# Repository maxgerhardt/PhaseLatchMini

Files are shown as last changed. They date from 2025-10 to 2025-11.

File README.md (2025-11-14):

# PhaseLatch Mini – STM32F103 Dual-ADC IQ USB Streamer

> Combined hardware + firmware + host tooling for a compact dual‑ADC I/Q capture platform.

## Overview

High-rate continuous streaming of interleaved dual ADC (I/Q) samples over USB Full‑Speed (FS) using only the built‑in CDC class on an STM32F103C8 ("Blue Pill" style) board. Companion Python host tools provide live visualization, FIFO bridging, raw capture, diagnostics, and throughput benchmarking.

> Status: Actively optimized. Current configured complex sample rate target: **210.5 k I/Q samples/sec** (`IQ_SAMPLE_RATE_HZ` = 210526) with sustained USB payload throughput >500 KiB/s. Timer PSC/ARR are selected at runtime by a search routine for the closest achievable rate; observed effective rate can be within a small delta of the target. ADC sampling time was reduced (now `ADC_SAMPLETIME_28CYCLES_5`) to reach this rate while maintaining conversion stability.

> Origin / Intended Use: Initially developed as a lightweight streaming engine for the [PhaseLoom](https://github.com/AndersBNielsen/PhaseLoom) project, but fully usable with any dual (I/Q) analog front end producing baseband signals on two STM32F1 ADC channels. 
Note: Phaseloom should be modified for best performance. Replace 22kOhm feedback caps with matched 47kOhm resistors and replace the output stage 50 ohms with 0 ohm.

https://www.youtube.com/watch?v=UEAtSE1PV44

---
## Hardware: PhaseLatch Mini
A 4‑layer purple PCB (Blue Pill footprint inspired) integrating two SMA input ports and on‑board ~100 kHz low‑pass filtering (~210 kHz complex baseband bandwidth). Designed around the STM32F103C8 in dual regular simultaneous ADC mode (ADC1 + ADC2) to stream interleaved I/Q samples over USB Full-Speed.

PhaseLatch Mini

### Key Features
- MCU: STM32F103C8 (72 MHz) LQFP‑48
- Dual simultaneous ADC (12‑bit each) packed into 32‑bit words (I lower 12 bits, Q upper 12 bits)
- 2 × edge‑mount SMA (J20 = I_IN, J21 = Q_IN)
- Integrated passive input filtering (inductor + capacitor network targeting ~100 kHz LPF per channel)
- USB‑C connector (USB2.0 FS, CDC class currently; raw/bulk class option planned)
- On‑board 8 MHz + 32.768 kHz crystals for stable system and RTC timing
- Ferrite bead + local bulk/decoupling for cleaner ADC rails
- Unused GPIOs forced to analog mode early for noise reduction (see `Quiet_Unused_Pins` in `main.c`)
- Headers for expansion / SWD / boot configuration

### Production Assets
All fabrication outputs live in `hardware/PhaseLatchMini/production`:
- `PhaseLatchMini.zip` – Gerber/drill bundle ready for PCB fab
- `bom.csv` – Bill of Materials (with LCSC part numbers for quick JLCPCB sourcing)
- `designators.csv` – Component reference list
- `positions.csv` – Pick‑and‑place XY + rotation for SMT assembly
- `netlist.ipc` – IPC netlist export

Direct link (relative): `hardware/PhaseLatchMini/production/PhaseLatchMini.zip`

### BOM Highlights
Representative components (from `bom.csv`):
- Decoupling: multiple 100 nF 0402 caps (C307331) near MCU and filter sections
- Filter / bulk caps: 22 nF, 220 nF, 470 nF mix shaping input response
- Inductors: six 10 µH (0805) parts forming LC sections for each channel’s low‑pass filtering / supply isolation
- USB-C receptacle: 16‑pin (HCTL HC-TYPE-C-16P-01A) with 5k1 CC resistors for proper orientation detection
- Ferrite bead (FB1) for USB / supply noise suppression
- Voltage regulator: MIC5504-3.3 (SOT‑23‑5) providing clean 3V3
- Crystals: 8 MHz main, 32.768 kHz low‑speed (RTC / optional precise timing)
- SMA edge connectors: matched pair for I and Q inputs

### Assembly Notes
- Clean flux residues near high‑impedance analog nodes (C1/C8 cluster) to keep leakage low.
- If performing hand assembly, solder the SMA edge connectors first to anchor board alignment, then USB, then fine‑pitch MCU.

### Filter Tuning
Current passive network targets ~100 kHz corner. For alternative bandwidths:
- Raise corner: decrease shunt capacitance (e.g., swap 470 nF → 220 nF or 22 nF depending on desired slope) or reduce inductance value.
- Lower corner: increase shunt capacitance or employ higher inductance (space permitting). Recalculate fc ≈ 1/(2π√(L·C_eq)).
- Mitigate source‑resistor induced tilt: include its resistance in design equations; keep initial shunt capacitors modest (≤10 nF) if a 50 Ω series is retained upstream.

## Firmware

- Dual ADC synchronous sampling packed as 32-bit little-endian words (I 12-bit + Q 12-bit inside two 16-bit lanes)
- Target sample rate `IQ_SAMPLE_RATE_HZ` (currently 210526) with dynamic TIM3 prescaler/period search (see `timer_trigger_init()` in `iq_adc.c`)
- ADC sampling time set to `ADC_SAMPLETIME_28CYCLES_5` for higher throughput (previous higher value limited rate)
- Circular DMA with half / full transfer interrupts
- Lock-free ring queue feeding USB transmit path
- ISR burst chaining (current chain limit 16 packets per IN completion) to minimize USB idle gaps
- Immediate DMA IRQ packet scheduling ("kick") to prime first packet of each half-buffer
- Optional diagnostic/stat packets suppressed in throughput builds
- Host tools for diagnostics, throughput, raw capture, FIFO bridging, live view

### Changing the Sample Rate
1. Edit `Inc/iq_adc.h` and set `#define IQ_SAMPLE_RATE_HZ <desired_rate>` (I/Q pairs per second).
2. Ensure the new rate is feasible: TIM3 must be able to realize it given 16-bit ARR and prescaler; the search code picks the closest achievable value.
3. If pushing higher rates:
   - Consider reducing ADC sampling time (`ADC_SAMPLETIME_x`) further, but watch noise/performance.
   - Monitor USB throughput counters (`FEED` command) for increased busy skips.
4. Rebuild and flash. Optionally measure actual achieved rate by counting `iq_dma_half_count` + `iq_dma_full_count` over a timed host interval.

### Verifying Achieved Rate
- After START, issue the `A` command periodically; note increments of half/full counts.
- Effective samples/sec ≈ ((delta_half + delta_full) * half_buffer_samples) / time_interval.
- Or capture a known duration with `host_test.py` and compute rows * rate.

---
## Repository Layout

```
platformio.ini              # Build environments & macro flags
src/                        # Firmware sources (USB, ADC, main logic)
Inc/ / include/             # Public headers
host_*.py                   # Python host utilities
lib/ test/                  # (Placeholders / future use)
```

Key firmware files:
- `src/main.c` – System init, main loop USB feeder (fallback scheduling & instrumentation)
- `src/iq_adc.c` / `Inc/iq_adc.h` – ADC+DMA+Timer configuration, DMA IRQ scheduling kick
- `src/usbd_conf.c` – Low-level USB callbacks, DataIn burst chaining logic
- `src/usbd_cdc_if.c` – CDC interface, command parser (A/F/STATS) & data write API
- `src/usbd_raw.c` (future / optional) – Raw class scaffolding (if transitioning from CDC for additional margin)

Host scripts (root directory):
- `host_diagnostics.py` – Passive capture, STATS delta decode, periodic monitor, USB descriptor info
- `host_throughput.py` – PyUSB bulk endpoint benchmark (raw vendor class / future); shows packet stats
- `host_raw_capture.py` – Robust raw USB (PyUSB or CDC) capture with quiet mode & BrokenPipe safety
- `host_iq_fifo.py` – Serial CDC → named FIFO adapter (u8 or cf32) for GQRX / GNU Radio
- `host_iq_live.py` – Terminal live IQ stats + sparklines / averages
- `host_test.py` – Simple START/STOP based capture, optional float32 output & basic stats
- `host_probe.py` – (Currently empty placeholder for future probing utilities)

---
## Build & Flash (PlatformIO)

Prerequisites:
- VS Code + PlatformIO extension (or `pio` CLI)

Clone & open project, then build one of the defined environments:

### PlatformIO Quickstart (Basics)

If you're new to PlatformIO, these are the minimal steps to get a firmware onto the board.

#### Option A: VS Code GUI
1. Install the "PlatformIO IDE" extension in VS Code.
2. Open this project folder (where `platformio.ini` resides).
3. Bottom status bar: pick the desired environment (e.g. `adc`).
4. Click the checkmark (Build). Wait for success.
5. Connect the board via USB (ensure it enumerates) and press the right arrow (Upload). If first flash fails, press/hold BOOT (if available) or use a serial/USB boot jumper sequence depending on your Blue Pill variant.
6. Use the plug icon (Monitor) or run a host script to interact.

#### Option B: CLI
Install PlatformIO Core (Python 3.11+ recommended):
```bash
pip install --upgrade platformio
```
From the project root:
```bash
# List environments defined in platformio.ini
pio run --list-targets

# Build the adc environment
pio run -e adc

# Upload (adjust -e if choosing another env)
pio run -e adc -t upload

# Open a serial monitor (Ctrl+C to exit)
pio device monitor -b 115200
```
If you see permission errors on macOS/Linux, you may need to adjust USB device permissions or add your user to the appropriate group (e.g. `dialout` on some Linux distros).

#### Common Upload Notes
- Some Blue Pill clones require setting/removing BOOT0 jumpers for the built-in ROM bootloader; after initial flash with a USB‑TTL adapter or ST-Link, subsequent USB CDC updates normally proceed automatically.
- For ST-Link users, ensure drivers and udev rules (Linux) are installed.
- If the device does not reset into the new firmware, press the hardware RESET button.

#### Serial Device Identification
On macOS you'll typically see `/dev/tty.usbmodem*`. On Linux, it may appear as `/dev/ttyACM0`. Use `pio device list` to enumerate.

Environments (see `platformio.ini`):
- `env:baseline` – Minimal USB baseline with reduced diagnostics (throughput focus pattern)
- `env:diag` – Heavier diagnostics enabled (ASCII stat chatter)
- `env:adc` – Active dual-ADC streaming (ENABLE_IQ + throughput suppressions)
- `env:adc_smoke` – Lower-intensity validation (extra ADC status prints)

Typical flow (using `env:adc`):
1. Select `adc` environment in PlatformIO
2. Build (should report flash usage ~30%, RAM ~55%)
3. Upload (DFU/serial depending on board configuration)
4. Open a serial monitor or run a host script (e.g. `python host_test.py --progress`)

If enumeration stalls: power cycle board or press reset. Heartbeat LED indicates main loop alive; rapid fallback pattern indicates SysTick/USB early issues.

---
## Runtime Commands (CDC)

Send as ASCII (line ending flexible, CR/LF accepted):
- `START` – Begin IQ streaming (if not already running)
- `STOP` – Halt streaming (host_test.py sends on exit)
- `A` – Print `ADCSTAT` line with ADC & DMA counters
- `F` – Print `FEED` line (USB feeder instrumentation)
- `STATS` – Legacy status snapshot (may be suppressed in throughput builds)

---
## Data Format

Each IQ sample pair is one 32-bit little-endian word composed of two 16‑bit containers produced by the STM32F1 dual regular simultaneous ADC mode:
```
Bits  0..11  : I (ADC1 12-bit result, right-aligned)
Bits 12..15  : Unused (always 0)  <-- upper 4 bits of lower 16-bit half-word
Bits 16..27  : Q (ADC2 12-bit result, right-aligned)
Bits 28..31  : Unused (always 0)  <-- upper 4 bits of upper 16-bit half-word
```

So effectively:
```
uint16_t I_lane = word & 0xFFFF;          // lower half-word
uint16_t Q_lane = (word >> 16) & 0xFFFF;  // upper half-word
uint16_t I_raw12 = I_lane & 0x0FFF;       // mask to 12 bits
uint16_t Q_raw12 = Q_lane & 0x0FFF;
```

The current `host_test.py` treats each 16-bit lane as a full-range unsigned sample and subtracts 32768. That overstates magnitude and uses the high (always zero) 4 bits. For correct 12‑bit centered scaling use:
```
float I = ((int)I_raw12 - 2048) / 2048.0f;   // ≈ [-1.0, +1.0)
float Q = ((int)Q_raw12 - 2048) / 2048.0f;
```
If you need signed 16-bit containers for downstream tooling, you can expand by left-shifting 4 (to occupy high bits) or replicate into 16-bit signed with:
```
int16_t I_s16 = ((int16_t)(I_raw12 ^ 0x800) - 0x800) << 4; // optional dynamic range padding
```
But most host paths should just mask & center at 2048.

---
## ADC / Timing Configuration

- Timer configuration is dynamic: `timer_trigger_init()` iterates prescaler values to find an ARR producing a rate closest to `IQ_SAMPLE_RATE_HZ`.
- Current target: 210526 samples/sec (complex pairs). Achieved rate is printed only via manual inspection (no direct text output yet); you can instrument `(best_rate)` variable in debugger if needed.
- ADC sampling time currently `ADC_SAMPLETIME_28CYCLES_5`; lowering further increases throughput but may degrade SNR and settling for higher source impedances.

Potential Adjustments:
- Increase `IQ_SAMPLE_RATE_HZ` (watch USB bandwidth & chain limit utilization).
- Change ADC sampling time for performance vs accuracy trade-off.
- Raise `chain_limit` (in `usbd_conf.c`) beyond 16 if the queue frequently stalls with residual samples and main loop fallback is minimal.

---
## USB Transfer Strategy & Optimizations
- Chain limit now 16 (see `usbd_conf.c`); README previously referenced 12—updated.
- DMA IRQ kick ensures first packet of each half-buffer is scheduled promptly.
- Remaining headroom: adopt packed 3-byte I12|Q12 mode (roadmap) or vendor RAW class for further rate increases.

---
## Instrumentation & Monitoring

Example FEED output (command `F`):
```
FEED loop=12345 isr=67890 busy=12 chain_max=11
```
Where:
- `loop` – Packets scheduled from main loop (fallback)
- `isr` – Packets scheduled from ISR path (burst + DMA kick)
- `busy` – Attempts skipped because endpoint currently active
- `chain_max` – Highest contiguous packets chained in a single IN completion

ADCSTAT example (`A`):
```
ADCSTAT half=1024 full=1024 drops=0
```
(Exact field names may vary—check live output.)

Use `host_diagnostics.py stats` for legacy STAT delta interpretation, if enabled in build.

---
## Host Utilities

| Script | Purpose |
|---|---|
| `host_test.py` | Simple START capture, optional float32 output, stats, graceful Ctrl+C |
| `host_iq_live.py` | Real-time terminal IQ level display, window averages, sparkline |
| `host_iq_fifo.py` | Serial → FIFO converter (u8 or cf32) for GQRX / fifo consumers |
| `host_raw_capture.py` | Raw byte dump with quiet & BrokenPipe-safe pipeline support |
| `host_diagnostics.py` | STATS deltas, passive capture, USB descriptor info |
| `host_throughput.py` | High-rate PyUSB bulk benchmark (raw class future) |
| `host_probe.py` | Placeholder for future probing tools |

### GQRX Integration (via FIFO)
- Set GQRX sample rate to match `IQ_SAMPLE_RATE_HZ` (e.g. 210526) or the nearest supported value.
1. Run FIFO bridge:
   ```
   python3 host_iq_fifo.py --fifo /tmp/iq_cf32.iq
   ```
2. In GQRX, set input to "UDP / File" or external source capable of reading named FIFO (Linux/macOS). Point to `/tmp/iq_cf32.fifo` with sample rate = `210526`.
3. Adjust gain/AGC in GQRX; confirm spectrum updates.

### Live View
```
python host_iq_live.py --port /dev/tty.usbmodemXYZ --window 512 --spark --interval 0.2
```
Shows min/max, window & running averages, and a small ASCII sparkline.

### Raw Capture Example
```
python host_raw_capture.py --out stream.bin --secs 5 --quiet
```
Then post-process with custom scripts or convert to complex floats.

---
## Performance Measurement

Quick rate check (CDC path):
```
python host_test.py --seconds 3 --progress
```
Or FEED counters before & after a timed interval to estimate packet dispatch accumulation.

PyUSB high-rate test (when using/adding raw vendor class):
```
python host_throughput.py --seconds 5 --progress
```

Interpretation updates:
- Bytes/sec ÷ 4 = complex samples/sec (current raw 32-bit mode).
- For future 3-byte packed mode bytes/sec ÷ 3 will apply.

---
## Troubleshooting

| Symptom | Suggestions |
|---|---|
| No `/dev/tty.usbmodem*` device | Replug USB, check cable, ensure board enumerates (dmesg / system log) |
| Streaming stalls after START | Check FEED counters (isr incrementing?). Confirm no flood of diagnostics enabled. |
| Throughput lower than expected | Ensure running `env:adc` (not `diag`), verify chain_max near limit, reduce host-side latency (no heavy printing) |
| Mis-scaled IQ values | Mask to 12 bits (0x0FFF) before centering; ensure not interpreting high unused bits |
| Broken pipe in pipeline capture | Use `host_raw_capture.py --quiet` (handles SIGPIPE and flush safety) |

---
## Roadmap / Future Ideas
- Maintain or push beyond 210 kS/s (USB packing & endpoint tuning)
- Optional tighter 24-bit (3-byte) packing (I12|Q12) – reduces bandwidth ~25%
- Vendor RAW class endpoint for marginal gains over CDC ACM
- Lightweight CRC / sequence tags for host-side drop detection
- Optional AGC / scaling in firmware (convert to centered 16-bit signed)
- Continuous integration tests for host scripts
- IQ gain/phase auto-calibration
- Expanded PhaseLatch Mini variants (higher‑resolution MCUs, external HS USB)

## License

(Choose and add a SPDX license header & file as appropriate, e.g. MIT or Apache-2.0.)

---
## Attribution / Notes

Developed as an incremental exploration of practical FS USB throughput & latency reduction techniques on resource-constrained MCUs while streaming synchronous dual-ADC data.

Contributions / suggestions welcome.

## Getting a PCB

## Production & Manufacturing
- The `hardware/production/` folder includes all needed files. 

This project is kindly sponsored by JLCPCB. They offer cheap, professional looking PCBs and super fast delivery.

Step 1: Get the gerber file zip package from the /hardware folder

Step 2: Upload to JLCPCB [https://jlcpcb.com/?from=Anders_N](https://jlcpcb.com/?from=Anders_N)

Upload

Step 3: Pick your color, surface finish and order.

Select settings

Save your choice

You can use these affiliate links to get a board for $2 and also get $54 worth of New User Coupons at: https://jlcpcb.com/?from=Anders_N

And in case you also want to order a 3D-printed case you can use this link. 
How to Get a $7 3D Printing Coupon: [https://3d.jlcpcb.com/?from=Anders3DP](https://jlc3dp.com/?from=Anders_N)

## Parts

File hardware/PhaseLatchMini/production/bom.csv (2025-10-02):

Designator | Footprint | Quantity | Value | LCSC Part #
C1, C10, C11, C13, C15, C8, C9 | 0402 | 7 | 100nF | C1525
C12, C14, C16, C17, C18, C19, C20, C21 | 0402 | 8 | 22nF | C1532
C2, C3 | 0402 | 2 | 15pF | C1548
C4, C7 | 0402 | 2 | 18pF | C1549
C5, C6 | 0805 | 2 | 1uF | C28323
D1 | 0805 | 1 | GREEN | C2297
FB1 | 0603 | 1 | FerriteBead_Small | C14709
J1, J3 | PinHeader_1x17_P2.54mm_Vertical | 2 | Conn_01x17_Pin
J2 | PinHeader_1x04_P2.54mm_Vertical | 1 | NC
J20 | SMA_Samtec_SMA-J-P-H-ST-EM1_EdgeMount | 1 | I_IN | C5301850
J21 | SMA_Samtec_SMA-J-P-H-ST-EM1_EdgeMount | 1 | Q_IN | C5301850
J4 | USB_C_Receptacle_HCTL_HC-TYPE-C-16P-01A | 1 | USB2.0_16P | C2894897
J5 | PinHeader_2x03_P2.54mm_Vertical | 1 | Boot
J6 | PinHeader_1x02_P2.54mm_Vertical | 1 | NC
L1, L2, L3, L4 | 0805 | 4 | 10uH | C1046
R1, R2, R4, R7 | 0402 | 4 | 10k | C25744
R13, R14 | 0402 | 2 | 5k1 | C25905
R3 | 0402 | 1 | 1k5 | C25867
SW3 | SW_SPST_TL3342 | 1 | BTN | C318884
U1 | LQFP-48_7x7mm_P0.5mm | 1 | STM32F103C8Tx | C8734
U5 | SOT-23-5 | 1 | MIC5504-3.3YM5 | C3021093
Y1 | Crystal_SMD_3225-4Pin_3.2x2.5mm | 1 | 8MHz | C5308002
Y2 | Crystal_SMD_3215-2Pin_3.2x1.5mm | 1 | 32768Hz | C32346

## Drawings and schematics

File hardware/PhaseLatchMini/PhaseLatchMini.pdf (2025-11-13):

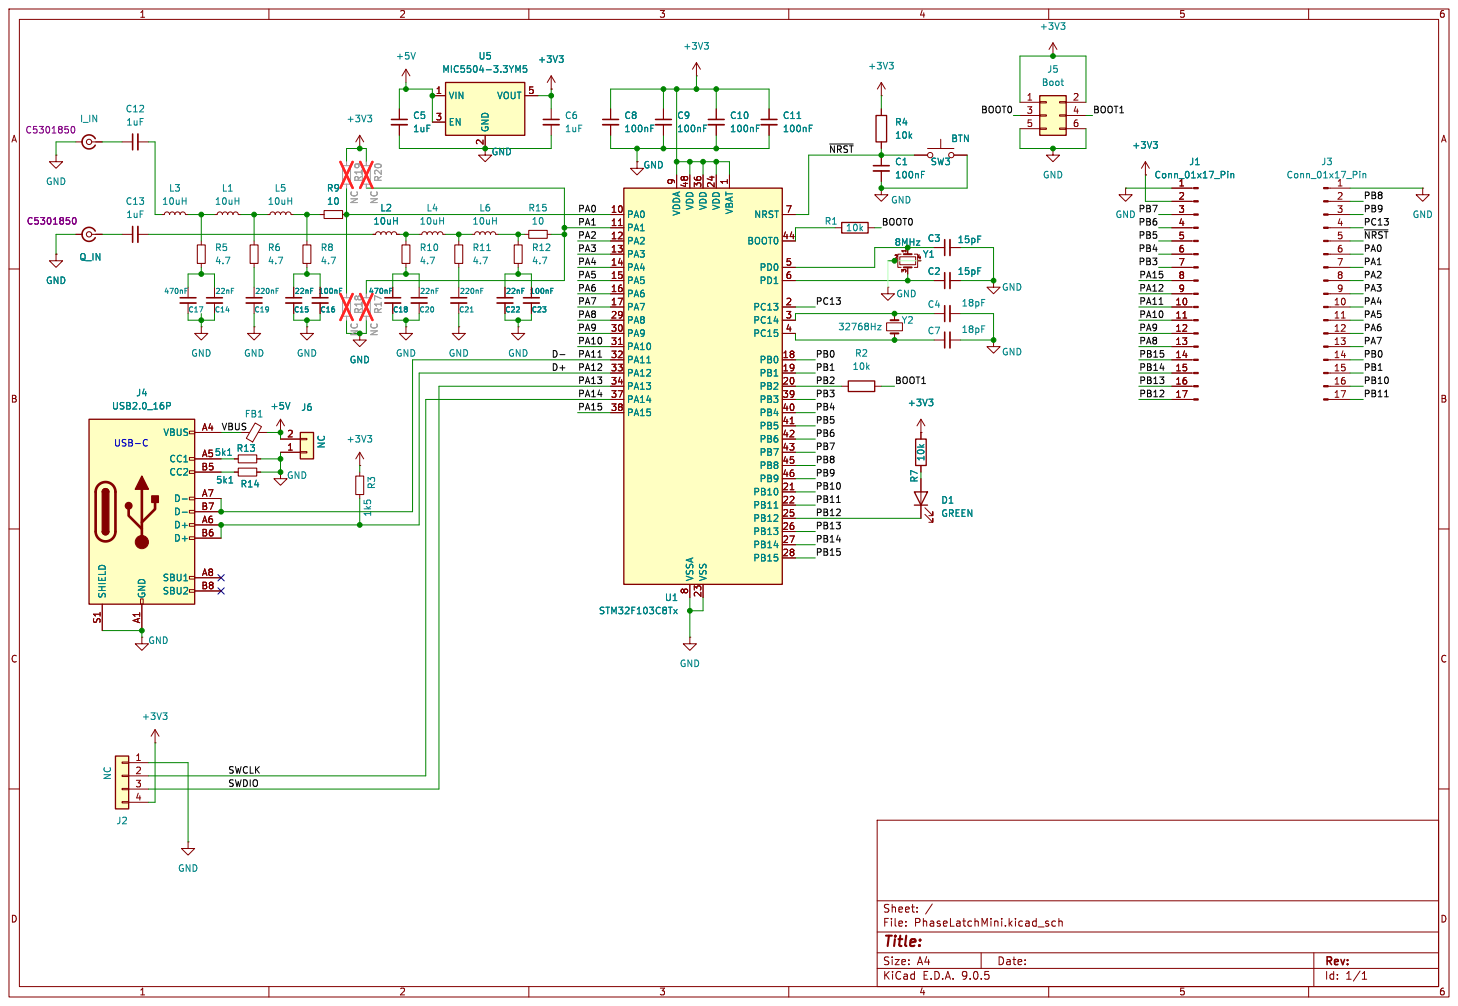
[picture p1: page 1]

1 VDD 24 VDD 36 VSS 23 VDD 48 VSSA

Id: 1/1 Title: File: PhaseLatchMini.kicad_sch Sheet: /

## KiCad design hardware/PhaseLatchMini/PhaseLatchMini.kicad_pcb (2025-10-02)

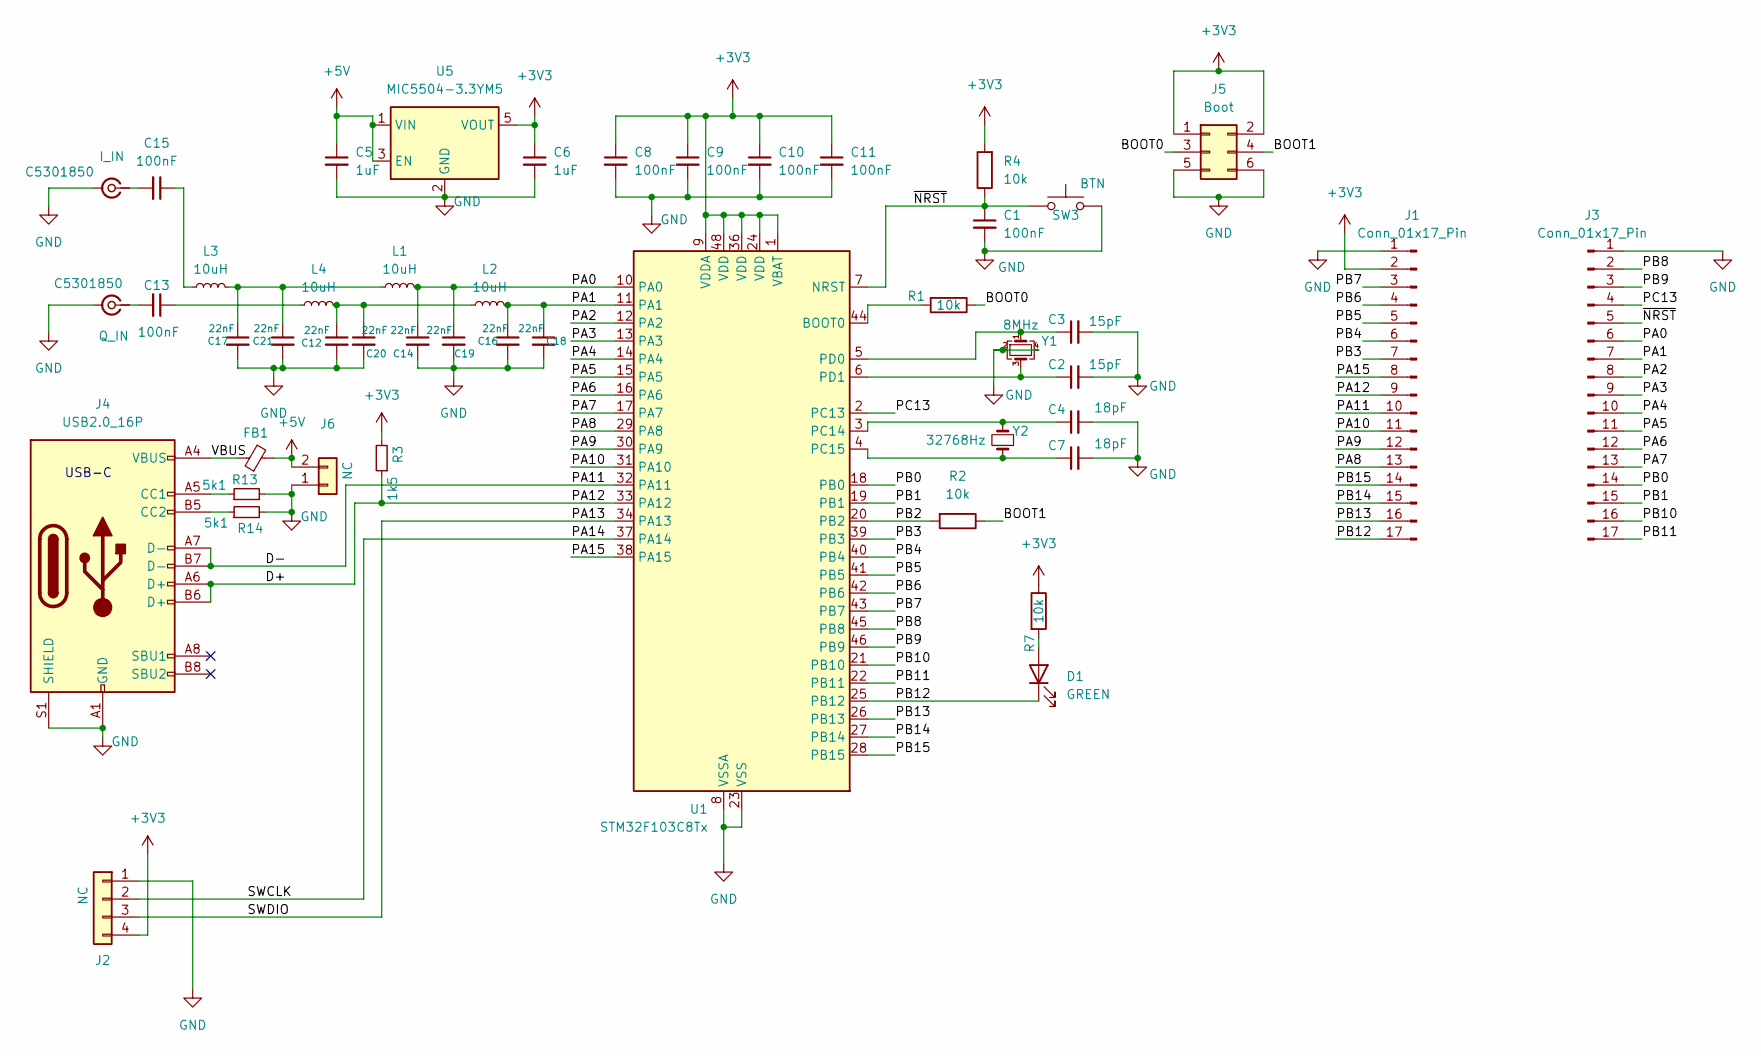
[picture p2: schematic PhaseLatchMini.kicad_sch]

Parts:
C1, C8, C9, C10, C11, C13, C15: 100nF; C_0402_1005Metric; LCSC C1525
C2, C3: 15pF; C_0402_1005Metric; LCSC C1548
C4, C7: 18pF; C_0402_1005Metric; LCSC C1549
C5, C6: 1uF; C_0805_2012Metric; LCSC C28323
C12, C14, C16, C17, C18, C19, C20, C21: 22nF; C_0402_1005Metric; LCSC C1532
D1: GREEN; LED_0805_2012Metric; LCSC C2297
FB1: FerriteBead_Small; L_0603_1608Metric; LCSC C14709
J1, J3: Conn_01x17_Pin; PinHeader_1x17_P2.54mm_Vertical
J2: NC; PinHeader_1x04_P2.54mm_Vertical
J4: USB2.0_16P; USB_C_Receptacle_HCTL_HC-TYPE-C-16P-01A; LCSC C2894897
J5: Boot; PinHeader_2x03_P2.54mm_Vertical
J6: NC; PinHeader_1x02_P2.54mm_Vertical
J20: I_IN; SMA_Samtec_SMA-J-P-H-ST-EM1_EdgeMount; LCSC C5301850
J21: Q_IN; SMA_Samtec_SMA-J-P-H-ST-EM1_EdgeMount; LCSC C5301850
L1, L2, L3, L4: 10uH; L_0805_2012Metric; LCSC C1046
R1, R2, R4, R7: 10k; R_0402_1005Metric; LCSC C25744
R3: 1k5; R_0402_1005Metric; LCSC C25867
R13, R14: 5k1; R_0402_1005Metric; LCSC C25905
SW3: BTN; SW_SPST_TL3342; LCSC C318884
U1: STM32F103C8Tx; LQFP-48_7x7mm_P0.5mm; LCSC C8734
U5: MIC5504-3.3YM5; SOT-23-5; LCSC C3021093
Y1: 8MHz; Crystal_SMD_3225-4Pin_3.2x2.5mm; LCSC C5308002
Y2: 32768Hz; Crystal_SMD_3215-2Pin_3.2x1.5mm; LCSC C32346

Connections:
+3V3: C6.1, C8.1, C9.1, C10.1, C11.1, J1.2, J2.4, J5.1, J5.2, R3.2, R4.2, R7.1, U1.1 (VBAT), U1.9 (VDDA), U1.24 (VDD), U1.36 (VDD), U1.48 (VDD), U5.5 (VOUT)
+5V: C5.1, FB1.2, J6.2, U5.1 (VIN), U5.3 (EN)
/BOOT0: J5.3, R1.1
/BOOT1: J5.4, R2.1
/D+: J1.9, J4.A6 (D+), J4.B6 (D+), R3.1, U1.33 (PA12)
/D-: J1.10, J4.A7 (D-), J4.B7 (D-), U1.32 (PA11)
/PA0: C14.1, C19.1, J3.6, L1.2, U1.10 (PA0)
/PA1: C16.1, C18.1, J3.7, L2.2, U1.11 (PA1)
/PA2: J3.8, U1.12 (PA2)
/PA3: J3.9, U1.13 (PA3)
/PA4: J3.10, U1.14 (PA4)
/PA5: J3.11, U1.15 (PA5)
/PA6: J3.12, U1.16 (PA6)
/PA7: J3.13, U1.17 (PA7)
/PA8: J1.13, U1.29 (PA8)
/PA9: J1.12, U1.30 (PA9)
/PA10: J1.11, U1.31 (PA10)
/PA13: J2.3, U1.34 (PA13)
/PA14: J2.2, U1.37 (PA14)
/PA15: J1.8, U1.38 (PA15)
/PB0: J3.14, U1.18 (PB0)
/PB1: J3.15, U1.19 (PB1)
/PB2: R2.2, U1.20 (PB2)
/PB3: J1.7, U1.39 (PB3)
/PB4: J1.6, U1.40 (PB4)
/PB5: J1.5, U1.41 (PB5)
/PB6: J1.4, U1.42 (PB6)
/PB7: J1.3, U1.43 (PB7)
/PB8: J3.2, U1.45 (PB8)
/PB9: J3.3, U1.46 (PB9)
/PB10: J3.16, U1.21 (PB10)
/PB11: J3.17, U1.22 (PB11)
/PB12: D1.1 (K), J1.17, U1.25 (PB12)
/PB13: J1.16, U1.26 (PB13)
/PB14: J1.15, U1.27 (PB14)
/PB15: J1.14, U1.28 (PB15)
/PC13: J3.4, U1.2 (PC13)
/VBUS: FB1.1, J4.A4 (VBUS), J4.A9 (VBUS), J4.B4 (VBUS), J4.B9 (VBUS)
/~NRST: C1.1, J3.5, R4.1, SW3.1, U1.7 (NRST)
GND: C1.2, C2.2, C3.2, C4.2, C5.2, C6.2, C7.2, C8.2, C9.2, C10.2, C11.2, C12.2, C14.2, C16.2, C17.2, C18.2, C19.2, C20.2, C21.2, J1.1, J2.1, J3.1, J4.A1 (GND), J4.A12 (GND), J4.B1 (GND), J4.B12 (GND), J4.S1 (SHIELD), J5.5, J5.6, J6.1, J20.2 (Ext), J21.2 (Ext), R13.2, R14.2, SW3.2, U1.8 (VSSA), U1.23 (VSS), U1.35 (VSS), U1.47 (VSS), U5.2 (GND), Y1.2, Y1.4
unnamed: C12.1, C20.1, L2.1, L4.2
unnamed: C13.1, L4.1
unnamed: C15.1, L3.1
unnamed: C17.1, C21.1, L1.1, L3.2
unnamed: D1.2 (A), R7.2
unnamed: J4.A5 (CC1), R13.1
unnamed: J4.B5 (CC2), R14.1
unnamed: C15.2, J20.1 (In)
unnamed: C13.2, J21.1 (In)
unnamed: R1.2, U1.44 (BOOT0)
unnamed: C4.1, U1.3 (PC14), Y2.2
unnamed: C7.1, U1.4 (PC15), Y2.1
unnamed: C3.1, U1.5 (PD0), Y1.1
unnamed: C2.1, U1.6 (PD1), Y1.3

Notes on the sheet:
USB-C

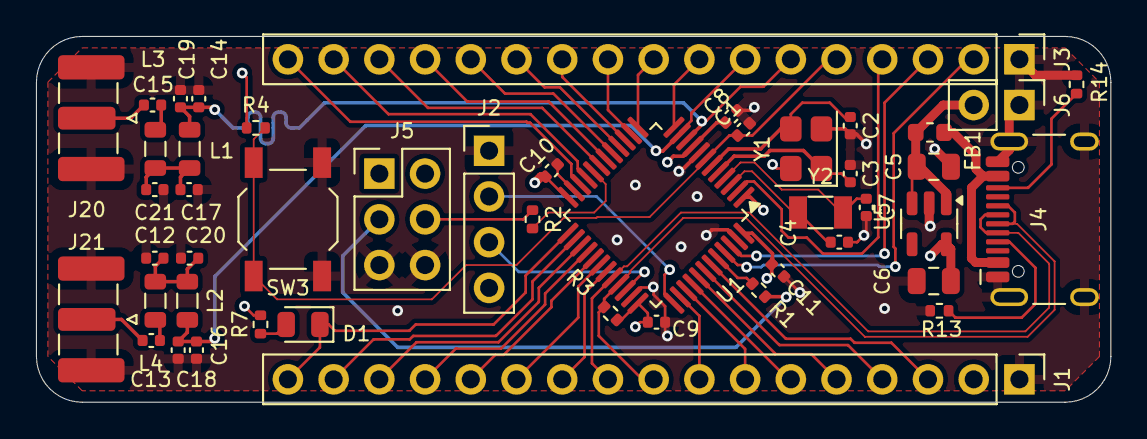
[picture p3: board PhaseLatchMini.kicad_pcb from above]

Board: 4 copper layers, 59.7 x 20.3 mm, 47 parts (0 on the bottom side), 54 nets.

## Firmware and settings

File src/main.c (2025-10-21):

// Minimal IQ streaming firmware: sends only raw ADC-packed words over CDC, no text.
#include "main.h"
#include "usbd_core.h"
#include "usbd_desc.h"
#include "usbd_cdc.h"
#include "usbd_cdc_if.h"
#include "usbd_def.h"
#if ENABLE_IQ
#include "iq_adc.h"
#endif
#include <string.h>

USBD_HandleTypeDef hUsbDeviceFS;
static void SystemClock_Config(void);
static void MX_GPIO_Init(void);
static void MX_USB_DEVICE_Init(void);
static void Quiet_Unused_Pins(void);

// Shared counters / stubs referenced by other modules (always provided)
volatile uint32_t feed_isr_pkts=0, feed_chain_max=0, feed_chain_current=0;
void dma_led_toggle(void){ HAL_GPIO_TogglePin(LED_GPIO_PORT, LED_PIN); }
#if ENABLE_IQ
volatile iq_chunk_t q[8];
volatile uint8_t q_head=0, q_tail=0;
volatile uint32_t adc_drops=0;
volatile uint32_t feed_loop_pkts=0, feed_busy_skips=0;
static void iq_cb(uint32_t *data, uint32_t count, uint8_t index){(void)index;uint8_t next=(q_head+1)&7; if(next==q_tail){adc_drops++;return;} q[q_head].ptr=data; q[q_head].words=count; q_head=next;}
#endif

int main(void){
  HAL_Init(); SystemClock_Config(); Quiet_Unused_Pins(); MX_GPIO_Init(); MX_USB_DEVICE_Init();
#if ENABLE_IQ
  iq_init(iq_cb);
  // Defer ADC start until USB configured (word boundary stability). Timeout fallback to avoid deadlock.
  uint32_t wait_start = HAL_GetTick();
  while(hUsbDeviceFS.dev_state != USBD_STATE_CONFIGURED) {
    if(HAL_GetTick() - wait_start > 2000) break; // 2s fallback
  }
  iq_start();
#endif
  static uint32_t last_led=0, spin=0; extern volatile uint8_t ep1_busy_flag; while(1){
    uint32_t now=HAL_GetTick();
    if(now==last_led){ if(++spin>500000){ HAL_GPIO_TogglePin(LED_GPIO_PORT,LED_PIN); spin=0; } }
    else if(now-last_led>=300){ HAL_GPIO_TogglePin(LED_GPIO_PORT,LED_PIN); last_led=now; spin=0; }
    if(hUsbDeviceFS.dev_state==USBD_STATE_CONFIGURED){
#if ENABLE_IQ
      while(ep1_busy_flag==0){
        if(q_tail==q_head) break; // no data
        iq_chunk_t c=q[q_tail];
        uint32_t bytes=c.words*4U; if(bytes>64) bytes=64; // 64-byte USB FS packet
        ep1_busy_flag=1;
        USBD_LL_Transmit(&hUsbDeviceFS, CDC_IN_EP,(uint8_t*)c.ptr, bytes);
        c.ptr+=bytes/4U; c.words-=bytes/4U;
        if(c.words==0) q_tail=(q_tail+1)&7; else q[q_tail]=c;
        feed_loop_pkts++;
        break;
      }
      if(ep1_busy_flag && q_tail!=q_head) feed_busy_skips++;
#endif
    }
  }
}

static void SystemClock_Config(void){
  RCC_OscInitTypeDef RCC_OscInitStruct={0}; RCC_ClkInitTypeDef RCC_ClkInitStruct={0};
  RCC_OscInitStruct.OscillatorType=RCC_OSCILLATORTYPE_HSE|RCC_OSCILLATORTYPE_HSI;
  RCC_OscInitStruct.HSEState=RCC_HSE_ON; RCC_OscInitStruct.HSEPredivValue=RCC_HSE_PREDIV_DIV1; RCC_OscInitStruct.HSIState=RCC_HSI_ON;
  RCC_OscInitStruct.PLL.PLLState=RCC_PLL_ON; RCC_OscInitStruct.PLL.PLLSource=RCC_PLLSOURCE_HSE; RCC_OscInitStruct.PLL.PLLMUL=RCC_PLL_MUL9;
  if(HAL_RCC_OscConfig(&RCC_OscInitStruct)!=HAL_OK) Error_Handler();
  RCC_ClkInitStruct.ClockType=RCC_CLOCKTYPE_HCLK|RCC_CLOCKTYPE_SYSCLK|RCC_CLOCKTYPE_PCLK1|RCC_CLOCKTYPE_PCLK2;
  RCC_ClkInitStruct.SYSCLKSource=RCC_SYSCLKSOURCE_PLLCLK; RCC_ClkInitStruct.AHBCLKDivider=RCC_SYSCLK_DIV1; RCC_ClkInitStruct.APB1CLKDivider=RCC_HCLK_DIV2; RCC_ClkInitStruct.APB2CLKDivider=RCC_HCLK_DIV1;
  if(HAL_RCC_ClockConfig(&RCC_ClkInitStruct, FLASH_LATENCY_2)!=HAL_OK) Error_Handler(); __HAL_RCC_USB_CLK_ENABLE();
}

static void MX_GPIO_Init(void){
  __HAL_RCC_GPIOC_CLK_ENABLE();
  GPIO_InitTypeDef GPIO_InitStruct={0};
  GPIO_InitStruct.Pin=LED_PIN; GPIO_InitStruct.Mode=GPIO_MODE_OUTPUT_PP; GPIO_InitStruct.Speed=GPIO_SPEED_FREQ_LOW; HAL_GPIO_Init(LED_GPIO_PORT,&GPIO_InitStruct);
  HAL_GPIO_WritePin(LED_GPIO_PORT, LED_PIN, GPIO_PIN_RESET);
}

static void Quiet_Unused_Pins(void){ /* Optionally configure unused pins as analog (implementation omitted for brevity) */ }

static void MX_USB_DEVICE_Init(void){
  /* Full-speed device init (speed param = 0). */
  USBD_Init(&hUsbDeviceFS, &FS_Desc, 0); USBD_RegisterClass(&hUsbDeviceFS, &USBD_CDC); USBD_CDC_RegisterInterface(&hUsbDeviceFS, &USBD_Interface_fops_FS); USBD_Start(&hUsbDeviceFS);
}

void Error_Handler(void){ __disable_irq(); while(1){ HAL_GPIO_TogglePin(LED_GPIO_PORT,LED_PIN); HAL_Delay(100);} }

#ifdef USE_FULL_ASSERT
void assert_failed(uint8_t *file, uint32_t line){ (void)file; (void)line; }
#endif

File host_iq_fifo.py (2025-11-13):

#!/usr/bin/env python3
"""
Bridge STM32 dual ADC (F103) CDC/raw streamed 32-bit packed IQ (ADC1+ADC2) into a FIFO as
interleaved complex samples for GQRX (File I/Q input) or other SDR tools.

Packing (STM32F1 dual regular simultaneous):
        Bits  0..11 : ADC1 result -> I (12-bit right-aligned)
        Bits 12..15 : zero padding
        Bits 16..27 : ADC2 result -> Q (12-bit right-aligned)
        Bits 28..31 : zero padding

Earlier versions mis-decodeds Q at bit 12; fixed to use bit 16.

Output format:
    cf32  : float32 complex (recommended for GQRX) written as contiguous <I,Q> pairs

Recommended for GQRX now: use --format cf32. In GQRX "File" I/Q input dialog select:
    Format: Complex float 32 (if available) OR use external pipe via gnuradio/Soapy for cf32.
If your GQRX build lacks native cf32 file mode, use an external converter to feed cf32 into GQRX.

Typical run for GQRX (220 kHz stream, prebuffer to avoid underrun):
    python host_iq_fifo.py --format cf32 --fifo /tmp/iq_cf32.iq --rate 220000 --prebuf 65536

Then in GQRX:
    1. Set input device to "File" and point to /tmp/iq_cf32.iq
    2. Sample rate: 220000 (or downsample inside GQRX DSP chain)
    3. Disable Loop so it treats growth as live
    4. Start after prebuffer completes

Use --swap-iq-output if downstream expects Q,I ordering.
Use --force-phase 0 in the new pure stream (no stray text) — automatic heuristics can be bypassed.

Ctrl+C to stop; script reports throughput and drop metrics.
"""
import argparse, glob, os, sys, time, math, statistics, stat, fcntl, struct, select, tty, termios
from collections import deque

try:
    import serial
except ImportError:
    print('ERROR: pyserial required (pip install pyserial)', file=sys.stderr)
    sys.exit(2)

DEFAULT_RATE = 140000  # complex samples/second (for info only)

ASCII_SKIP_THRESHOLD = 0.90  # skip chunk if mostly printable text and contains 'STAT'


def find_port(explicit=None):
    if explicit:
        return explicit
    ports = sorted(glob.glob('/dev/tty.usbmodem*'))
    if not ports:
        raise SystemExit('No /dev/tty.usbmodem* device found')
    return ports[0]

def ensure_fifo(path):
    if os.path.exists(path):
        st_mode = os.stat(path).st_mode
        if not stat.S_ISFIFO(st_mode):
            raise SystemExit(f'Path {path} exists and is not a FIFO')
    else:
        os.mkfifo(path)


def decode_block(buf, out_container, *, zero_i=False, zero_q=False, invert_q=False, phase_correction_deg=0.0):
    """Decode packed 32-bit IQ words into cf32 float32 pairs (little-endian dual12).

    Parameters:
      buf          : bytes-like, length multiple of 4
      out_container: list to which packed '<ff' bytes pairs will be appended
      zero_i/zero_q: if True, force channel to center value (debug)
      invert_q     : invert Q channel polarity around center (debug)
    """
    def lane_words(off):
        b0 = buf[off]; b1 = buf[off+1]; b2 = buf[off+2]; b3 = buf[off+3]
        # little-endian per 16-bit lane: low byte first
        i16 = b0 | (b1 << 8)
        q16 = b2 | (b3 << 8)
        return i16, q16

    pack = struct.pack
    scale = 2048.0
    center = 2048
    # precompute rotation for phase correction
    if phase_correction_deg:
        rad = phase_correction_deg * (math.pi/180.0)
        rot_cos = math.cos(rad)
        rot_sin = math.sin(rad)
    else:
        rot_cos = 1.0; rot_sin = 0.0
    for off in range(0, len(buf), 4):
        i16, q16 = lane_words(off)
        i_raw = i16 & 0x0FFF
        q_raw = q16 & 0x0FFF
        if zero_i: i_raw = center
        if zero_q: q_raw = center
        if invert_q and not zero_q:
            q_raw = (center*2 - q_raw)
        fi = (i_raw - center) / scale
        fq = (q_raw - center) / scale
        # apply phase correction rotation to complex sample (I + jQ)
        if rot_sin != 0.0:
            ri = fi * rot_cos - fq * rot_sin
            rq = fi * rot_sin + fq * rot_cos
        else:
            ri = fi; rq = fq
        out_container.append(pack('<ff', ri, rq))

# analyze_samples removed per request: alignment/metric diagnostics and spectral helpers disabled.


# estimate_image_alpha removed: image-alpha estimation (FFT-based spectral helpers) disabled per request.


# refine_image_alpha removed: iterative spectral refinement disabled per request.

## __main__ guard moved to end of file. Duplicate doc block removed.

DEFAULT_RATE = 140000  # complex samples/second (for info only)

ASCII_SKIP_THRESHOLD = 0.90  # skip chunk if mostly printable text and contains 'STAT'


def find_port(explicit=None):
    if explicit:
        return explicit
    ports = sorted(glob.glob('/dev/tty.usbmodem*'))
    if not ports:
        raise SystemExit('No /dev/tty.usbmodem* device found')
    return ports[0]

def ensure_fifo(path):
    if os.path.exists(path):
        st_mode = os.stat(path).st_mode
        if not stat.S_ISFIFO(st_mode):
            raise SystemExit(f'Path {path} exists and is not a FIFO')
    else:
        os.mkfifo(path)


"""(Removed duplicate decode_block implementation.)"""

# analyze_samples removed: alignment/metric diagnostics disabled


# estimate_image_alpha removed: spectral helpers disabled


# refine_image_alpha removed: iterative spectral refinement disabled

# spectral_phase_select removed: FFT-based spectral alignment helper disabled per request.
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
